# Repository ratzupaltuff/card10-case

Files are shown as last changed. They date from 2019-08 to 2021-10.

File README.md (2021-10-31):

# CCC Camp 2019 Badge Case

This repository contains scad and stl-files for a case for the card10 badge. The contents of this repository are also published on [thingiverse](https://www.thingiverse.com/thing:3769330). On thingiverse are some pictures of the printed case. Github has a stl-viewer so you can click on the stl-files too to get a preview.

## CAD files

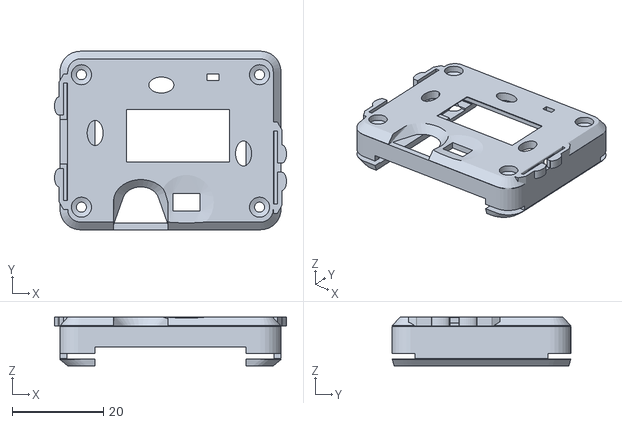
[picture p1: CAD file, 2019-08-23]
builds/card10-complete.stl
50.8 x 39.1 x 10.7

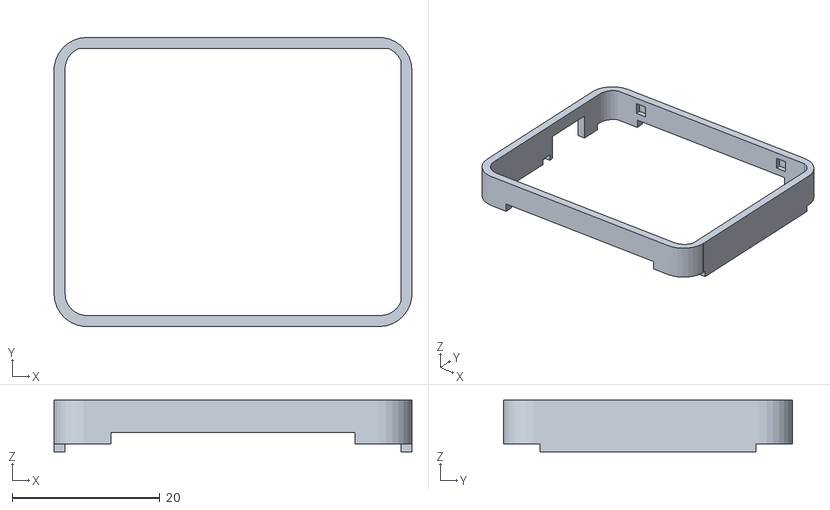
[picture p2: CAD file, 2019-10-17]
builds/card10-side.stl
48.4 x 39.1 x 7.00

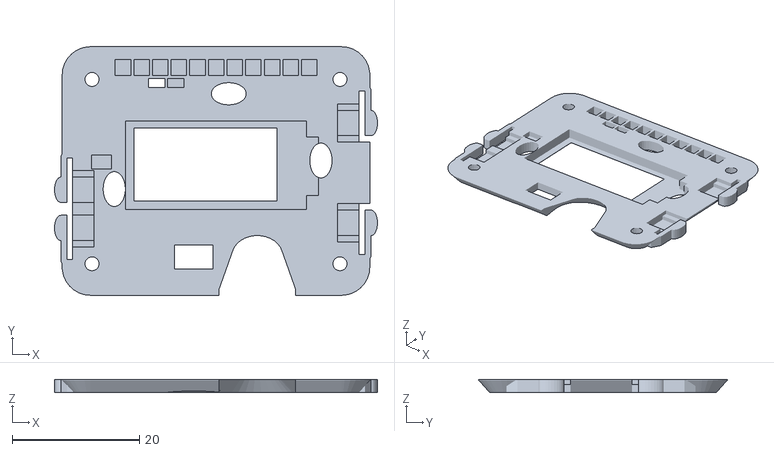
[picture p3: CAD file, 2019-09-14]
builds/card10-top.stl
50.8 x 39.1 x 2.00

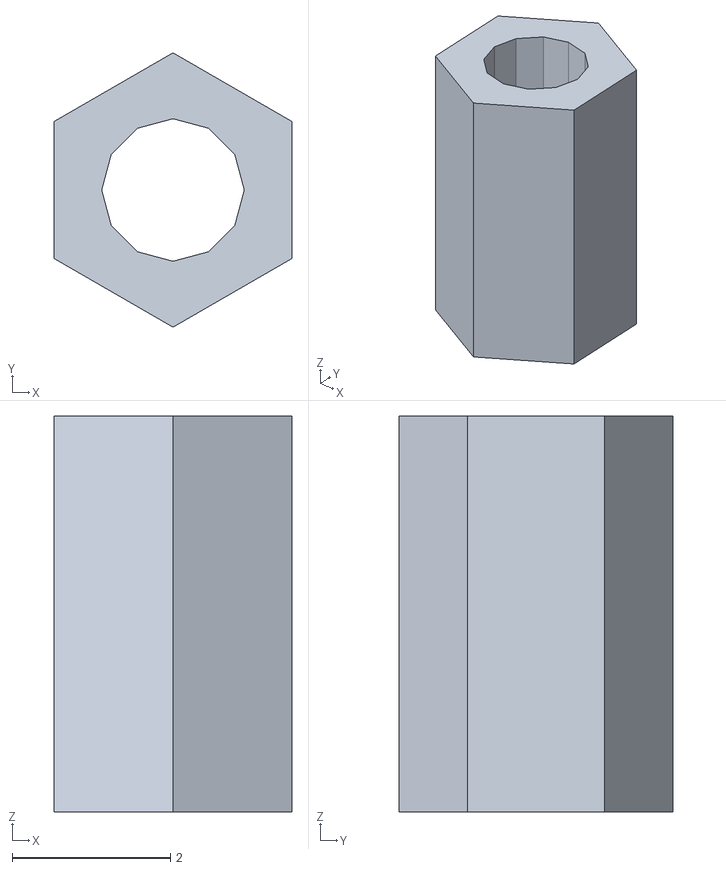
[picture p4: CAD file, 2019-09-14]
builds/card10-spacer.stl
3.00 x 3.46 x 5.00

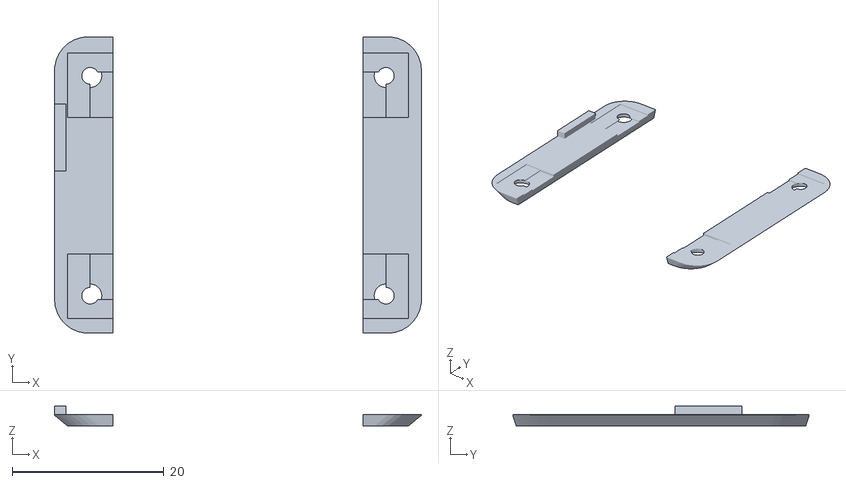
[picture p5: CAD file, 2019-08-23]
builds/card10-bottom.stl
48.4 x 39.1 x 2.60

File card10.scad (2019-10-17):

//$fa = 0.5;
$fs = 0.5;

//printerSettings
printerOffset = 0.2;
caseThickness = 1.5;
layerHeight = 0.16;

//bottompcb
bottomPcbThickness = 1+printerOffset/2;
bottomPcbWidth = 45;
bottomPcbHeight = 38.2;
bottomEdgeDiameter = 4.5;

//wristband
wristbandHolderWidth = 6;
wristbandHolderHeight = 0.6;
wristbandHolderHeightAroundScrew = 0.2;
wristbandHolderInsetY = 0.5;

//contactPins
contactPinWidth = 33;
contactPinHeigth = 3;
contactPinDistanceX = 6;

//screws
bottomScrewDistanceX = 3;
bottomScrewDistanceY = 4.5;
topScrewDistanceX = bottomScrewDistanceX;
topScrewDistanceY = 3.25;
ScrewDistanceX = 39;
ScrewDistanceY = 29;
screwHeadDiameter = 4+printerOffset;
screwHeadHeight = 0.5;
screwDiameter = 2;

//spacer
distancePcbs = 5;
topPcbOffset = bottomScrewDistanceY-topScrewDistanceY;

//topPcb
topCaseThickness = 2;
topPcbWidth = bottomPcbWidth;
topPcbHeight = 35.7;
topPcbEdgeDiameter = 2.75;
topPcbThickness = bottomPcbThickness;

//buttons
buttonHeight = 1.5;
buttonWidth = 3.8+printerOffset;
buttonDepth = 3.2+printerOffset;
buttonSolderPadsWidth = 1;
buttonSolderPadHeight = buttonHeight/2;

//buttonPositions
button1x = 0;
button1Y = 23.5-printerOffset/2;

button2x = 0;
button2Y = 7.8-printerOffset/2;

button3x = topPcbWidth-buttonDepth+printerOffset/2;
button3Y = 7-printerOffset/2;

button4x = topPcbWidth-buttonDepth+printerOffset/2;
button4Y = 13-printerOffset/2;

//display and connector
displayHeight = 13.5+printerOffset*2;
displayWidth = 28+printerOffset*2;
displayThickness = topCaseThickness-layerHeight;
displayCableHeight = 9+printerOffset;
displayCableWidth = 2+printerOffset;

//please check those two values, may vary due to flexible mount
//measured from top pcb corner to corner of display (both bottom-left)
displayPositionX = 8.5-printerOffset;
displayPositionY = 12-printerOffset;
displayCablePositonY = 2-printerOffset/2;

//actual visible area of display
displayBacklightHeight = 11.5;
displayBacklightWidth = 22.5;
//position of visible area relative to bottom-left corner of display
displayBacklightPosX = 4.6;
displayBacklightPosY = 1.3;

//Heartbeat sensor
sensorHeight = 3.6 + printerOffset;
sensorWidth = 5.8 + printerOffset;
sensorThickness = 1.5;
sensorPosX = 23.1 - printerOffset/2; //23
sensorPosY = 2.5 -printerOffset/2; //2.8
heartbeatSensorOvalDiameter = 12;

//frontResistor
resistorHeight = 1.2 + printerOffset;
resistorWidth = 2.6;
resistorDepth = 1.2;
resistorX = 27.5;
resistorY = 31;

//frontLed/ir sensor
ledHeight = resistorHeight;
ledWidth = resistorWidth;
ledThickness = topCaseThickness+1; //-0.15
ledPosX = resistorX + 3;
ledPosY = resistorY;

//rgbLeds
rgbLedsHeight = 2.25+printerOffset;
rgbLedsWidth = 2.25+printerOffset;
rgbLedsThickness = topCaseThickness-layerHeight;
rgbLedsBeginPosX = 6.7-printerOffset/2;
//LEFT edge of the last rgbLed
rgbLedsEndPosX = 36-printerOffset/2;
rgbLedsPosY = 33-printerOffset/2;
rgbLedsNumber = 11;
rgbLedsDistance = (rgbLedsEndPosX-rgbLedsBeginPosX)/(rgbLedsNumber-1);

//card10 finger contact pins
contactPinSmallDiameter = 8;
contactPinLargeDiameter = 12;
conatctPinThickness = topCaseThickness;
contactPinLeftX = 16;
contactPinRightX = 32.5;
contactPinY = 4.5;
contactPinScaleYFactor = 0.8;

//rocket leds
rocketRoundPosX = 6;
rocketRoundPosY = 19.5;
rocketLinesPosX = 20.5;
rocketLinesPosY = 30;
rocketLeafPosX = 38.5;
rocketLeadPosY = 15;

//jumperSpare
jumperHeight = 2+printerOffset;
jumperWidth = 3+printerOffset;
jumperThickness = 1;
jumperPosX = 39-printerOffset/2;
jumperPosY = 18.3-printerOffset/2;

//klicker
klickerDistance = 0.9;
klickerLength = 5;
klickerMountWidth = 2;
klickerArmThickness = 1;
klickerCylinderPosX = 5;
klickerCylinderMaxWidth = 1;
klickerCylinderScaleFactor = 0.5;
klickerAngle = 30;

//sideCover
sideCoverHeight = bottomPcbThickness+topPcbThickness+distancePcbs-printerOffset;
sideCoverThickness = caseThickness;

//typeC
typeCHeight = 3.2+printerOffset;
typeCWidth = 9+printerOffset;
typeCPosY = 19.5+topPcbOffset; //fromTopPlate

//pcbOverhangs
pcbOverhangThickness = 2;
pcbOverhangDepth = 1;
pcbOverhangPosY = 18;

//pcb spacer
spacerThickness = 3;
spacerHeight = distancePcbs;
spacerInnerDiameter = 1.6 + printerOffset;

//choose which elements to display
//bottom cover
    //bottomPcbCover();
//top cover  
    //positionedTopCover();
    //topCover();
//side cover
    //positionedSideCover();
    sideCover();
//whole case
    //case();
    
//Spacer
    //positionedSpacer();
    //pcbSpacerHex();
    

module case(){
    positionedTopCover();
    positionedSideCover();
    bottomPcbCover();
}
    
module positionedTopCover(){
    translate([0,0,distancePcbs+bottomPcbThickness+topPcbThickness+caseThickness])topCover();
}

module positionedSideCover(){
    translate([0,0,caseThickness+printerOffset/2])sideCover();
}

module positionedSpacer(){
    translate([bottomScrewDistanceX+ScrewDistanceX,bottomScrewDistanceY,caseThickness+bottomPcbThickness+spacerHeight/2+printerOffset/2])pcbSpacerHex();
}

module bottomPcbCover(){
    difference(){
        hull(){
            difference(){
                cube([bottomPcbWidth,bottomPcbHeight,caseThickness]);
                //edge cutting
                rotate([0,0,180])bottomEdgeNegative();
                translate([bottomPcbWidth,bottomPcbHeight,0])rotate([0,0,0])bottomEdgeNegative();
                translate([0,bottomPcbHeight,0])rotate([0,0,90])bottomEdgeNegative();
                translate([bottomPcbWidth,0,0])rotate([0,0,-90])bottomEdgeNegative();
            }
            translate([0,0,caseThickness-0.1])sideCoverRaw(0.1);
        }

        //screw cuttings
        translate([bottomScrewDistanceX,bottomScrewDistanceY,-wristbandHolderHeightAroundScrew])screwNegative(caseThickness);
        translate([bottomScrewDistanceX+ScrewDistanceX,bottomScrewDistanceY,-wristbandHolderHeightAroundScrew])screwNegative(caseThickness);
        translate([bottomScrewDistanceX,bottomScrewDistanceY+ScrewDistanceY,-wristbandHolderHeightAroundScrew])screwNegative(caseThickness);
        translate([bottomScrewDistanceX+ScrewDistanceX,bottomScrewDistanceY+ScrewDistanceY,-wristbandHolderHeightAroundScrew])screwNegative(caseThickness);
    
        //wristbandCuttings
        translate([contactPinDistanceX,-contactPinHeigth,0])cube([contactPinWidth,bottomPcbHeight*2,caseThickness]);
        
        
        translate([bottomScrewDistanceX,bottomScrewDistanceY-wristbandHolderInsetY,caseThickness-wristbandHolderHeight])cube([ScrewDistanceX,wristbandHolderWidth,wristbandHolderHeight]);
        
        translate([bottomScrewDistanceX,bottomScrewDistanceY + ScrewDistanceY - wristbandHolderWidth+wristbandHolderInsetY,caseThickness-wristbandHolderHeight])cube([ScrewDistanceX,wristbandHolderWidth,wristbandHolderHeight]);
        
        translate([0,bottomScrewDistanceY-wristbandHolderWidth/2,caseThickness-wristbandHolderHeightAroundScrew])cube([bottomPcbWidth,wristbandHolderWidth*1.5-wristbandHolderInsetY,wristbandHolderHeightAroundScrew]);
        
        translate([0,bottomScrewDistanceY+wristbandHolderWidth/2+ScrewDistanceY-(wristbandHolderWidth*1.5-wristbandHolderInsetY),caseThickness-wristbandHolderHeightAroundScrew])cube([bottomPcbWidth,wristbandHolderWidth*1.5-wristbandHolderInsetY,wristbandHolderHeightAroundScrew]);
    
    }
    
    //typeC overlap
    translate([-sideCoverThickness-printerOffset,typeCPosY+printerOffset,caseThickness])cube([sideCoverThickness,typeCWidth-printerOffset*2,bottomPcbThickness]);
}

module bottomPcbCoverFull(){
    difference(){
        hull(){
            difference(){
                cube([bottomPcbWidth,bottomPcbHeight,caseThickness]);
                //edge cutting
                rotate([0,0,180])bottomEdgeNegative();
                translate([bottomPcbWidth,bottomPcbHeight,0])rotate([0,0,0])bottomEdgeNegative();
                translate([0,bottomPcbHeight,0])rotate([0,0,90])bottomEdgeNegative();
                translate([bottomPcbWidth,0,0])rotate([0,0,-90])bottomEdgeNegative();
            }
            translate([0,0,caseThickness-0.1])sideCoverRaw(0.1);
        }

        //screw cuttings
        translate([bottomScrewDistanceX,bottomScrewDistanceY,0])screwNegative(caseThickness);
        translate([bottomScrewDistanceX+ScrewDistanceX,bottomScrewDistanceY,0])screwNegative(caseThickness);
        translate([bottomScrewDistanceX,bottomScrewDistanceY+ScrewDistanceY,0])screwNegative(caseThickness);
        translate([bottomScrewDistanceX+ScrewDistanceX,bottomScrewDistanceY+ScrewDistanceY,0])screwNegative(caseThickness);
    
        //contactPinCuttings
        translate([contactPinDistanceX,-contactPinHeigth,0])cube([contactPinWidth,contactPinHeigth*2,caseThickness]);
        translate([contactPinDistanceX,bottomPcbHeight-contactPinHeigth,0])cube([contactPinWidth,contactPinHeigth*2,caseThickness]);
    
    }
    
    //typeC overlap
    translate([-sideCoverThickness-printerOffset,typeCPosY+printerOffset,caseThickness])cube([sideCoverThickness,typeCWidth-printerOffset*2,bottomPcbThickness]);
}
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

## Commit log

2019-07-21 Add bottom and top plate-cover
    [card10.scad]
2019-07-21 Add first build
    [card10-complete.stl]
2019-07-21 Add hole for front led
    [card10.scad]
2019-07-22 Add button extender to top plate
    [card10.scad]
2019-07-22 Add renderings for buttom and top plate
    [card10-bottom.stl, card10-top.stl]
2019-07-22 Adjust values for topCase, begin adding sideCase
    [card10-top.stl, card10.scad]
2019-07-22 Finish sideCase, adjust values for topCase
    [card10-side.stl, card10-top.stl, card10.scad]
2019-07-22 Make sideCase larger to fit over pcb
    [card10-side.stl, card10.scad]
2019-07-22 Update complete build
    [card10-complete.stl]
2019-07-23 Add round edges to bottom
    [card10-bottom.stl, card10.scad]
2019-07-23 Add round edges to topCover
    [card10-top.stl, card10.scad]
2019-07-23 Render new complete model with round edges
    [card10-complete.stl]
2019-07-23 Refactor and delete some unused lines
    [card10.scad]
2019-08-15 Add Cuttings for 11 Leds and ECG contact pins
    [card10-complete.stl, card10-top.stl, card10.scad]
2019-08-21 adapted case to camp vers. and add cutouts for rocketLeds
    [card10-top.stl, card10.scad]
2019-08-22 Adapted dimensions of pulseSensor
    [card10-top.stl, card10.scad]
2019-08-22 Adapt dimensions for ir-transceiver and leds
    [card10-top.stl, card10.scad]
2019-08-23 Adapt Dimensions for bottom and side cover
    [card10-bottom.stl, card10-complete.stl, card10-side.stl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]
2019-08-23 new Cutout for Ecg
    [card10-complete.stl, card10-side.stl, card10-top.stl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]
2019-09-14 Add replacement for hex-distancer
    [card10-spacer.stl, card10.scad]
2019-09-14 Rotate top cover the right way to print it directly
    [card10-top.stl]
2019-10-17 Add thin areas for better visibilty of status LEDs
    [card10-side.stl, card10.scad]
